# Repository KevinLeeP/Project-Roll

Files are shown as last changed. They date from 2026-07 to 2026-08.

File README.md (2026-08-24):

<h1>Project Roll </h1>
<p1>Project Roll is a spherical robot that achieves omni-directional movement using omni-wheels and a hamster ball drive mechanism. The robot features a custom Smart Power Distribution Board made in KiCAD that centralizes power management and connections between sensors, motors, and ESP-32 MCU onto one board. The software written in C++ is currently a work in progress.</p1>

## OnShape CAD
[Onshape Link](https://cad.onshape.com/documents/6bff8405cef2444ed844f4c5/w/1237cbf75ed8744d7832d4f6/e/41b5c13e098610f260b44efa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)

## Images
Project_Roll1
Project_Roll2
Project_Roll3
Project_Roll4
<p1> Custom power distribution board </p1>

BB-8_ASM (2)
<p1> Robot CAD showing internals </p1>

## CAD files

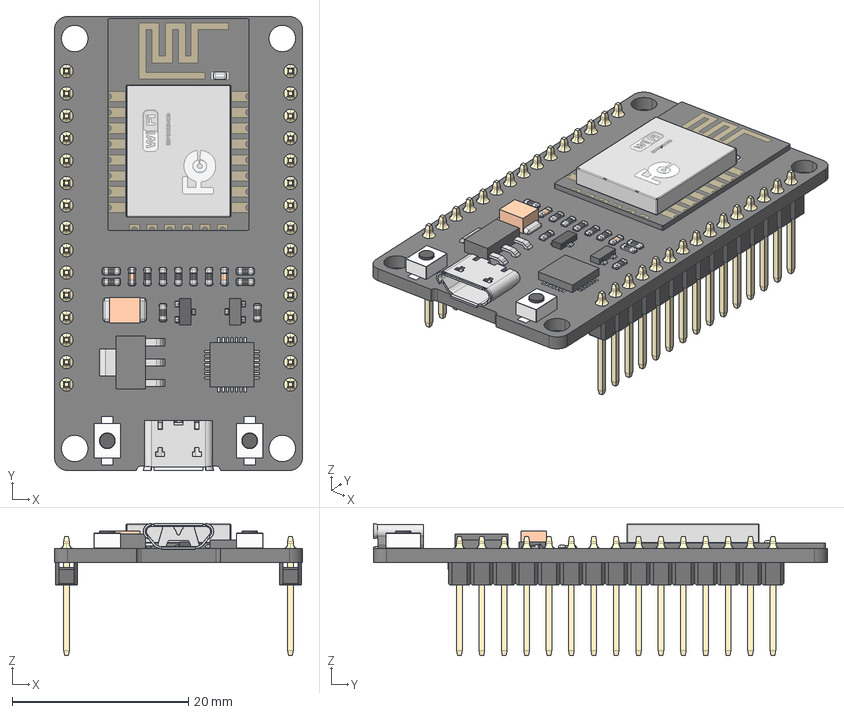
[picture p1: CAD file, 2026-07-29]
BB8_3D/esp32_dev_kit_v1_asm.stp
28.1 x 51.5 x 15.0 mm
PCB
PIN x 30
WIFI_CARD_2
RECTANGULARCHIP_2
MICROCHIP_2
TANCHIP_2
TRANSISTOR_3-LEG_2
RESISTOR1_2 x 11
RESISTOR2-32_2 x 2
TRANSISTOR_3-LEG2_2
BUTTONFLASH-13_2 x 2
BUTTONFLASH-14_2 x 2
USB_SOCKET_2

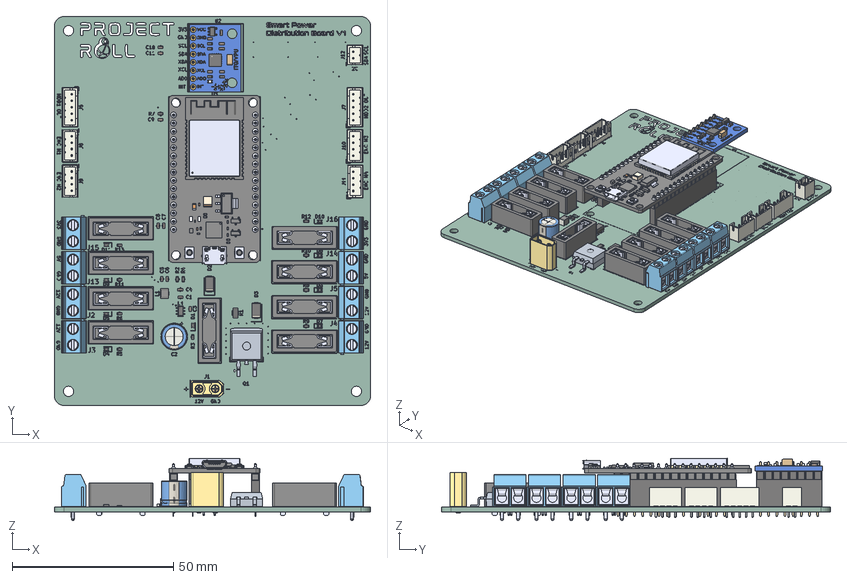
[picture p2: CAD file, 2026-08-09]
Roll_PDB.step
98.2 x 120.8 x 19.4 mm
3557-2--3DModel-STEP-510211 x 9
C_0603_1608Metric x 11
JST_PH_B4B-PH-K_1x04_P2.00mm_Vertical x 4
D_0603_1608Metric x 9
JST_PH_B5B-PH-K_1x05_P2.00mm_Vertical x 2
TSOT-23-6
CP_Radial_D8.0mm_P3.50mm
TB002-500-02P_Blue - S x 8
XT30UPB-M--3DModel-STEP-510211
R_0603_1608Metric x 13
R_1206_3216Metric
L_1210_3225Metric
PinSocket_1x15_P2.54mm_Vertical x 2
ESP32-DEVKIT-V1
PinSocket_1x08_P2.54mm_Vertical
PCB
trou1
trou002
trou003
trou004
trou005
trou006
trou007
trou008
Text_X
Symb_Y
Symb_X
Text_Y
Text_VCC
Text_GND
Text_SCL
Text_SDA
Text_XDA
Text_XCL
Text_ADO
Text_INT
R_0603_1608Metric001
R_0603_1608Metric002
R_0603_1608Metric003
C_0603_1608Metric001
C_0603_1608Metric002
C_0603_1608Metric003
Corps002
Corps001 (Mirror #1)
C_0603_1608Metric004
C_0603_1608Metric005
LED_0603_1608Metric_Castellated
QFN_16_1EP_4x4mm_P065mm_EP21x21mm
Text_ITGMPU
SOT_23_5
Corps001
PinHeader_1x08_P2.54mm_Vertical
Roll_PDB 1.55.1
JST_PH_B2B-PH-K_1x02_P2.00mm_Vertical
D_SMA x 2
Project_Roll_silkscreen x 2
Project_Roll_PCB

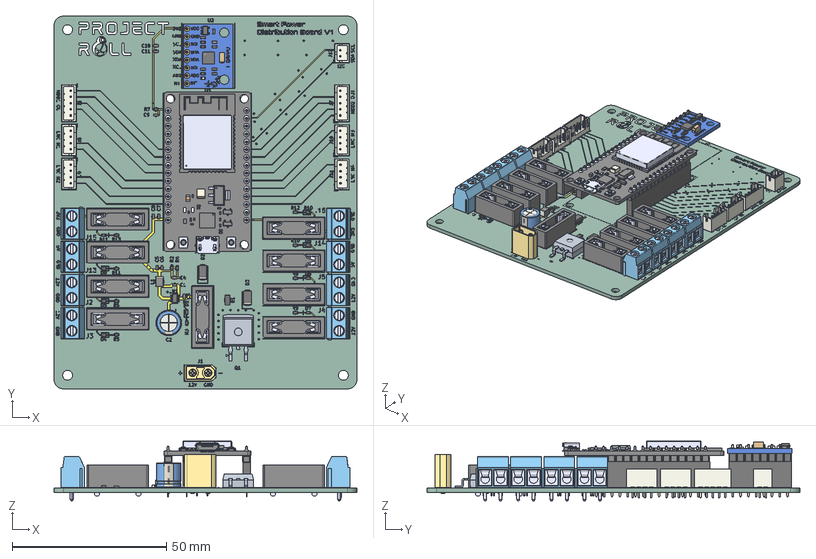
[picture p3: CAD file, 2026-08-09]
.step
98.2 x 120.8 x 19.4 mm
3557-2--3DModel-STEP-510211 x 9
C_0603_1608Metric x 11
JST_PH_B4B-PH-K_1x04_P2.00mm_Vertical x 4
D_0603_1608Metric x 9
JST_PH_B5B-PH-K_1x05_P2.00mm_Vertical x 2
TSOT-23-6
CP_Radial_D8.0mm_P3.50mm
TB002-500-02P_Blue - S x 8
XT30UPB-M--3DModel-STEP-510211
R_0603_1608Metric x 13
R_1206_3216Metric
L_1210_3225Metric
PinSocket_1x15_P2.54mm_Vertical x 2
ESP32-DEVKIT-V1
PinSocket_1x08_P2.54mm_Vertical
PCB
trou1
trou002
trou003
trou004
trou005
trou006
trou007
trou008
Text_X
Symb_Y
Symb_X
Text_Y
Text_VCC
Text_GND
Text_SCL
Text_SDA
Text_XDA
Text_XCL
Text_ADO
Text_INT
R_0603_1608Metric001
R_0603_1608Metric002
R_0603_1608Metric003
C_0603_1608Metric001
C_0603_1608Metric002
C_0603_1608Metric003
Corps002
Corps001 (Mirror #1)
C_0603_1608Metric004
C_0603_1608Metric005
LED_0603_1608Metric_Castellated
QFN_16_1EP_4x4mm_P065mm_EP21x21mm
Text_ITGMPU
SOT_23_5
Corps001
PinHeader_1x08_P2.54mm_Vertical
.step 1.55.1
JST_PH_B2B-PH-K_1x02_P2.00mm_Vertical
D_SMA x 2
Project_Roll_copper
Project_Roll_via
Project_Roll_silkscreen x 2
Project_Roll_PCB

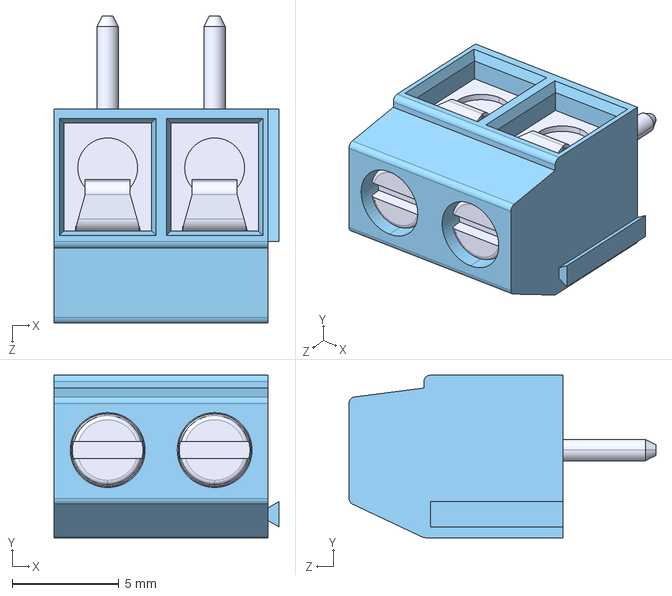
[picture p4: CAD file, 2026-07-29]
BB8_3D/TB002-500-02BE--3DModel-STEP-1.STEP
10.5 x 7.60 x 14.4 mm

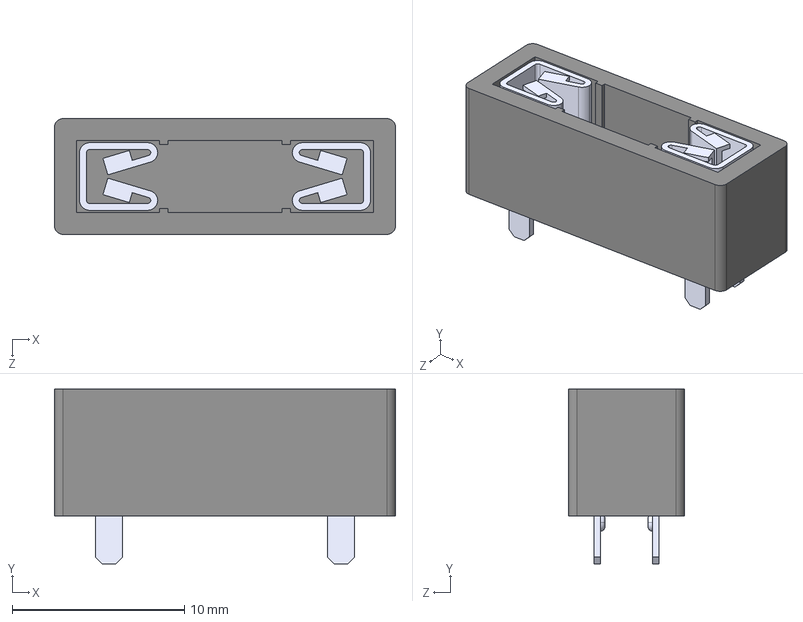
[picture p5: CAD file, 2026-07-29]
BB8_3D/3557-2--3DModel-STEP-510211.STEP
19.8 x 10.2 x 6.73 mm

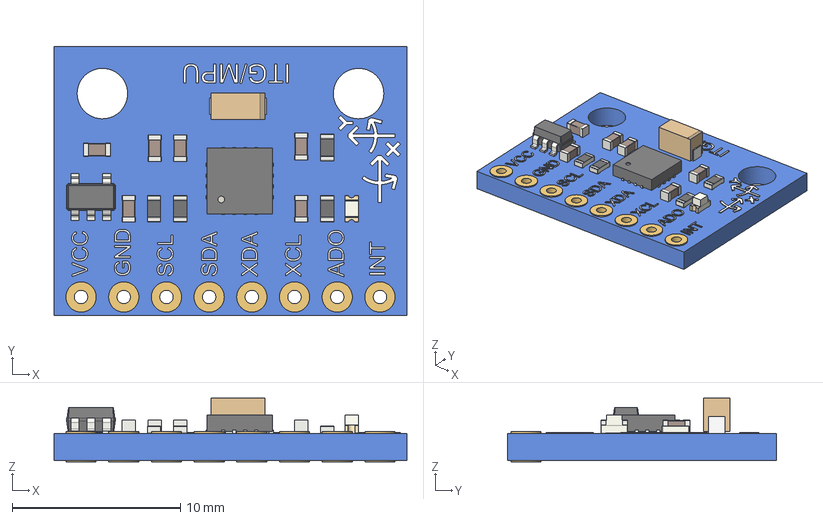
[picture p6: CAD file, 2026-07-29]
BB8_3D/GY-521_MPU6050 Accelerometer.step
21.0 x 16.0 x 3.80 mm
PCB
trou1
trou002
trou003
trou004
trou005
trou006
trou007
trou008
Text_X
Symb_Y
Symb_X
Text_Y
Text_VCC
Text_GND
Text_SCL
Text_SDA
Text_XDA
Text_XCL
Text_ADO
Text_INT
R_0603_1608Metric
R_0603_1608Metric001
R_0603_1608Metric002
R_0603_1608Metric003
C_0603_1608Metric
C_0603_1608Metric001
C_0603_1608Metric002
C_0603_1608Metric003
Corps002
Corps001 (Mirror #1)
C_0603_1608Metric004
C_0603_1608Metric005
LED_0603_1608Metric_Castellated
QFN_16_1EP_4x4mm_P065mm_EP21x21mm
Text_ITGMPU
SOT_23_5
Corps001

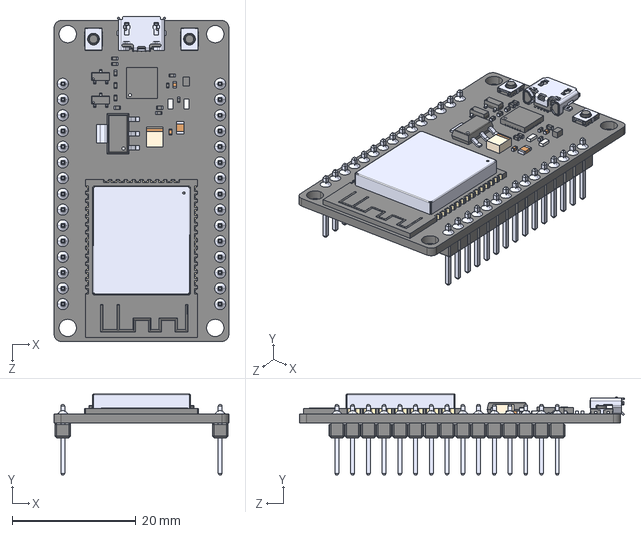
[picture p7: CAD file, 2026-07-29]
BB8_3D/ESP32-DEVKIT-V1.step
28.2 x 13.1 x 52.5 mm

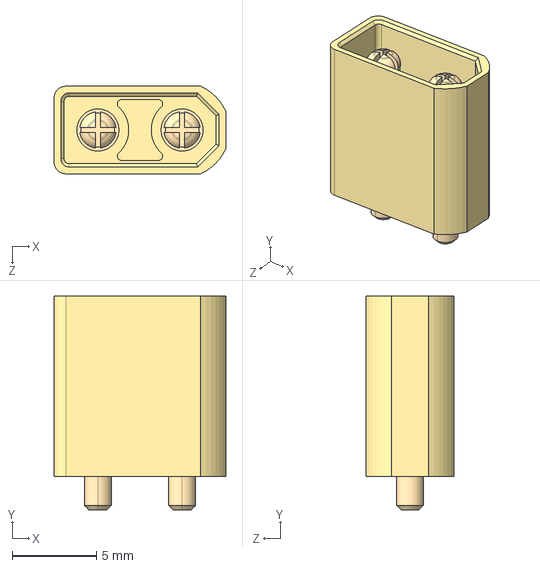
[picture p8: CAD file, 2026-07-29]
BB8_3D/XT30UPB-M--3DModel-STEP-510211.STEP
10.2 x 12.7 x 5.20 mm

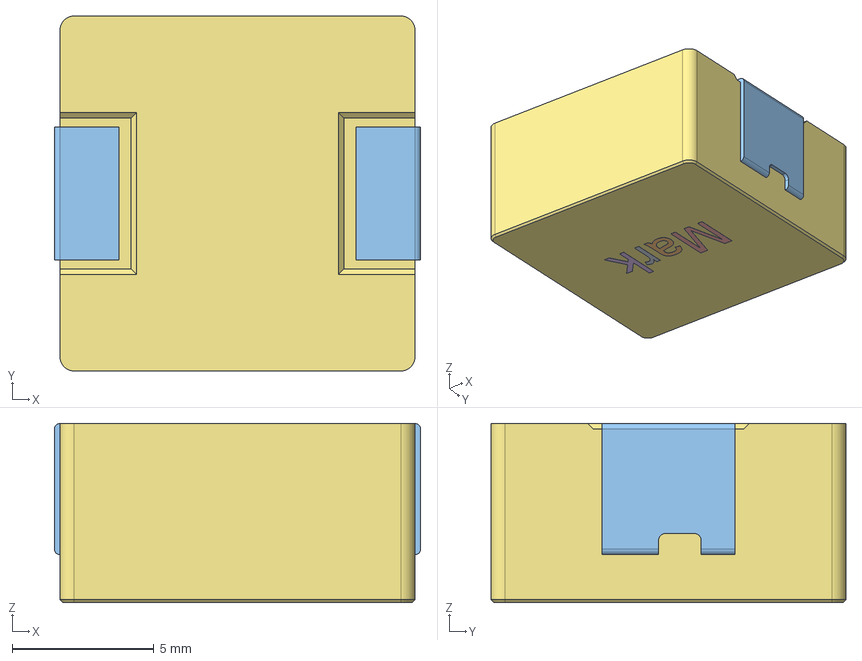
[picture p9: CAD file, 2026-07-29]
BB8_3D/SRP1265A series.stp
12.9 x 12.5 x 6.30 mm

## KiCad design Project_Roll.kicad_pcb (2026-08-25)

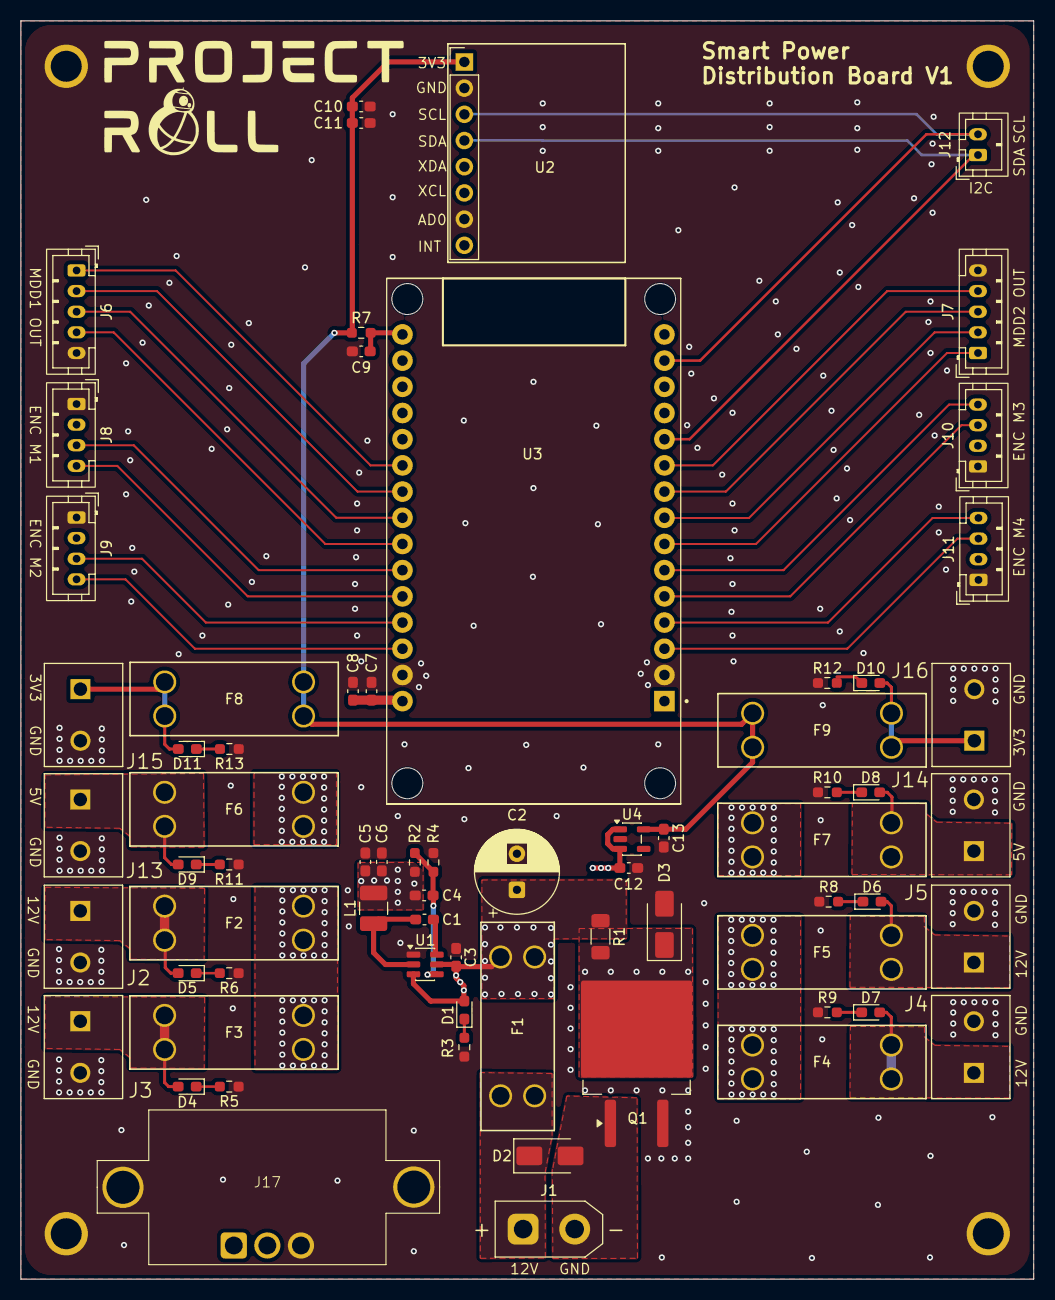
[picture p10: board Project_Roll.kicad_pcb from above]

Board: 4 copper layers, 98.2 x 122.0 mm, 73 parts (0 on the bottom side), 46 nets.

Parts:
C1, C8, C11: 0.1uF; C_0603_1608Metric_Pad1.08x0.95mm_HandSolder
C2: 220uF; CP_Radial_D8.0mm_P3.50mm
C3: 10uF; C_0603_1608Metric_Pad1.08x0.95mm_HandSolder
C4: 10pF; C_0603_1608Metric_Pad1.08x0.95mm_HandSolder
C5, C6: 22uF; C_0603_1608Metric_Pad1.08x0.95mm_HandSolder
C7, C9, C10, C12, C13: 1uF; C_0603_1608Metric_Pad1.08x0.95mm_HandSolder
D1, D4, D5, D6, D7, D8, D9, D10, D11: LTST-C193TBKT-5A; D_0603_1608Metric_Pad1.05x0.95mm_HandSolder
D2: SMAJ15CA; D_SMA
D3: SMAJ15A; D_SMA
F1: 20A; CONN_3557-2_KEY
F2, F3, F4, F5, F6, F7, F8, F9: 10A; CONN_3557-2_KEY
H1, H2, H3, H4: MountingHole_Pad; MountingHole_3.2mm_M3_DIN965_Pad
J1: TB002-500-02BE; AMASS_XT30UPB-F_1x02_P5.0mm_Vertical
J2, J3, J4, J5, J13, J14, J15, J16: TB002-500-02BE; CUI_TB002-500-02BE
J6, J7: Conn_01x05; JST_PH_B5B-PH-K_1x05_P2.00mm_Vertical
J8, J9, J10, J11: Conn_01x04; JST_PH_B4B-PH-K_1x04_P2.00mm_Vertical
J12: Conn_01x02; JST_PH_B2B-PH-K_1x02_P2.00mm_Vertical
J17: Conn_01x03; Voltage Meter
L1: 3.3uH; L_1210_3225Metric_Pad1.42x2.65mm_HandSolder
Q1: IRFS7430TRLPBF; TO-263-2
R1: 10k; R_1206_3216Metric_Pad1.30x1.75mm_HandSolder
R2: 56.2k; R_0603_1608Metric_Pad0.98x0.95mm_HandSolder
R3, R5, R6, R8, R9: 2k; R_0603_1608Metric_Pad0.98x0.95mm_HandSolder
R4, R7: 10k; R_0603_1608Metric_Pad0.98x0.95mm_HandSolder
R10, R11: 620; R_0603_1608Metric_Pad0.98x0.95mm_HandSolder
R12, R13: 270; R_0603_1608Metric_Pad0.98x0.95mm_HandSolder
U1: AP62300TWU; TSOT-23-6
U2: GY-521; PinHeader_1x08_P2.54mm_Vertical
U3: ESP32-DEVKIT-V1; MODULE_ESP32_DEVKIT_V1
U4: MIC5504-3.3YM5; SOT-23-5

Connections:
+3V3: C10.1, C11.1, C13.1, F8.1, F9.1, R7.1, U2.1 (VCC), U4.5 (VOUT)
+5V: C4.1, C5.1, C6.1, C7.1, C8.1, C12.1, F6.1, F7.1, J8.2, J9.2, J10.2, J11.2, L1.2, R2.1, U3.30 (VIN), U4.1 (VIN), U4.3 (EN)
+12V: C2.1, C3.1, D1.2 (A), F1.2, F2.1, F3.1, F4.1, F5.1, J17.1, J17.2, R1.1, U1.3 (IN), U1.5 (EN)
GND: C2.2, C3.2, C5.2, C6.2, C7.2, C8.2, C9.2, C10.2, C11.2, C12.2, C13.2, D3.2 (A2), H1.1 (1_1), H2.1 (1_1), H3.1 (1_1), H4.1 (1_1), J2.2, J3.2, J4.2, J5.2, J6.5, J7.5, J8.1, J9.1, J10.1, J11.1, J13.2, J14.2, J15.2, J16.2, J17.3, Q1.3 (S), R3.1, R4.2, R5.1, R6.1, R8.1, R9.1, R10.1, R11.1, R12.1, R13.1, U1.1 (GND), U2.2 (GND), U2.7 (AD0), U3.2 (GND), U3.29 (GND), U4.2 (GND)
GND_BAT: D2.2 (A2), J1.2, Q1.1 (D)
I2C_SCL: J12.2, U2.3 (SCL), U3.14 (D22)
I2C_SDA: J12.1, U2.4 (SDA), U3.11 (D21)
M1_DIR: J6.1, U3.21 (D32)
M1_ENC_A: J8.3, U3.25 (D27)
M1_ENC_B: J8.4, U3.26 (D14)
M1_PWM: J6.2, U3.22 (D33)
M2_DIR: J6.3, U3.23 (D25)
M2_ENC_A: J9.3, U3.27 (D12)
M2_ENC_B: J9.4, U3.28 (D13)
M2_PWM: J6.4, U3.24 (D26)
M3_DIR: J7.1, U3.7 (TX2)
M3_ENC_A: J10.3, U3.5 (D4)
M3_ENC_B: J10.4, U3.6 (RX2)
M3_PWM: J7.2, U3.8 (D5)
M4_DIR: J7.4, U3.10 (D19)
M4_ENC_A: J11.3, U3.3 (D15)
M4_ENC_B: J11.4, U3.4 (D2)
M4_PWM: J7.3, U3.9 (D18)
unnamed: D1.1 (K), R3.2
unnamed: D3.1 (A1), Q1.2 (G), R1.2
unnamed: D4.2 (A), F3.2, J3.1
unnamed: D4.1 (K), R5.2
unnamed: D5.2 (A), F2.2, J2.1
unnamed: D5.1 (K), R6.2
unnamed: D6.2 (A), F5.2, J5.1
unnamed: D6.1 (K), R8.2
unnamed: D7.2 (A), F4.2, J4.1
unnamed: D7.1 (K), R9.2
unnamed: D8.2 (A), F7.2, J14.1
unnamed: D8.1 (K), R10.2
unnamed: D9.2 (A), F6.2, J13.1
unnamed: D9.1 (K), R11.2
unnamed: D10.2 (A), F9.2, J16.1
unnamed: D10.1 (K), R12.2
unnamed: D11.2 (A), F8.2, J15.1
unnamed: D11.1 (K), R13.2
unnamed: C1.1, U1.6 (BST)
unnamed: C4.2, R2.2, R4.1, U1.4 (FB)
unnamed: C1.2, L1.1, U1.2 (SW)
unnamed: C9.1, R7.2, U3.16 (EN)
V_BATT: D2.1 (A1), F1.1, J1.1

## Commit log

2026-07-29 Created repo for Project Roll
    [.step, 3557-2--3DModel-STEP-510211.STEP, ESP32-DEVKIT-V1.step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]
2026-07-29 Update README with project details and CAD link
    Added project description and OnShape CAD link to README.
2026-08-09 TVS Diode fix and layout changes
    [.step, Project_Roll.kicad_pcb, Project_Roll.kicad_sch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]
2026-08-24 Vias for power connections
    [Project_Roll-B_Cu.gbr, Project_Roll-B_Mask.gbr, Project_Roll-B_Paste.gbr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]
2026-08-24 fixed 5v fill
    [Project_Roll.kicad_pcb, Project_Roll.kicad_sch]
2026-08-24 cleaned up fills
    [Project_Roll-B_Cu.gbr, Project_Roll-B_Mask.gbr, Project_Roll-B_Paste.gbr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]
2026-08-25 Separated schematic into sheets
    [Project_Roll.kicad_pcb, Project_Roll.kicad_sch, breakout_connectors.kicad_sch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]

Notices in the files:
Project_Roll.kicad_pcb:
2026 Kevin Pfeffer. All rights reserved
